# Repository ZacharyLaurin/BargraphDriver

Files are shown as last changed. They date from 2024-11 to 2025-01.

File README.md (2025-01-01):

# Bargraph Driver

For IN-13 / IN-9 Neon Tubes

## Description

Wave

This is a small 21x24mm driver module PCB designed for a single IN-13 or IN-9 neon bargraph tube. It fits on a breadboard and multiple modules can be chained together with U-shaped headers. Each module has an 8-bit DAC with a fixed address, controlled via I2C. The potentiometer is used to adjust the maximum glow length. Here is four tubes acting as a (not very accurate) spectrum analyzer: https://www.youtube.com/shorts/-yOVEOMO8Xs

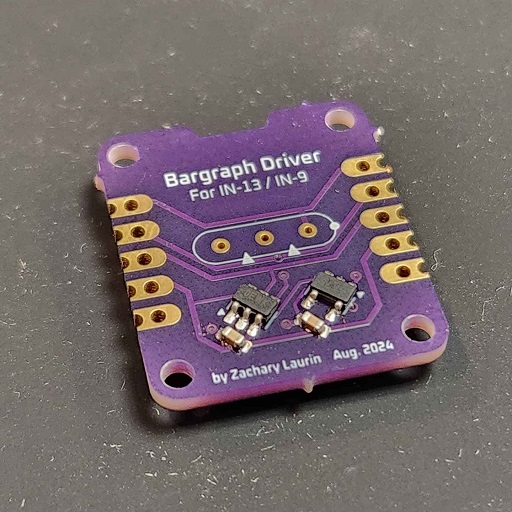
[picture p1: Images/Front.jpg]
Front

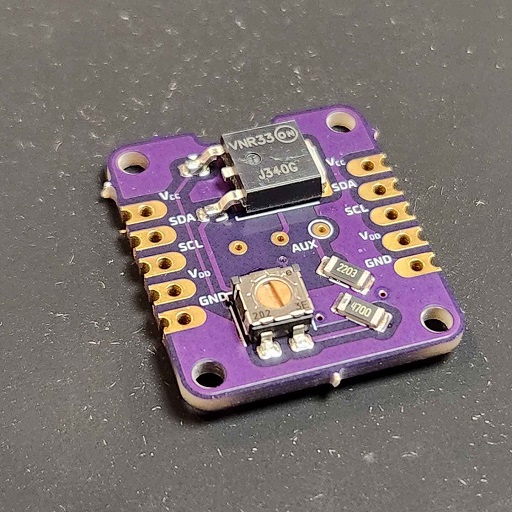
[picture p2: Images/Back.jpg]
Back


In the resources folder you will find the datasheet for the IN-13 as well as the font I used on the silkscreen. I have also included the BOM. I personally got all of the components from Mouser and the boards printed at OSHPark. To power the tubes I am using a [NCH6300HV](https://omnixie.com/products/nch6300hv-nixie-hv-power-module) and to control them an Arduino UNO with this [MCP47X6 library](https://github.com/uChip/MCP47X6).

### Notes

* The SDA pad is right next to the +150V one so watch out as to not accidentally short them while soldering.
* Although the MCP4706's datasheet says that there are eight available addresses, it seems that most electronic suppliers only stock the first four. In my case I had to use two I2C buses to drive as many tubes as I wanted to (and had to do two chains of four tubes).
* You need some sort of frame to hold the tubes in place. I recommend the use of large zip ties near the base to keep them straight.

## Author

Zachary Laurin

## Version History

* 1.0.0
    * Initial Release

## License

This project is licensed under the GNU GPLv3 License - see the LICENSE.md file for details

## Acknowledgments

Thanks a lot to the users of the Arduino, KiCad EDA and Nixie Tubes Discord servers as well as to the people of neonixie-l and the EEVblog forum for their help.

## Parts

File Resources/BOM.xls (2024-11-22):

BARGRAPH DRIVER
Mouser # | Mfr. # | Manufacturer | Customer # | Description | RoHS | Lifecycle | Order Qty. | Price (CAD) | Ext.: (CAD)
863-MJD340G | MJD340G | onsemi |  | Bipolar Transistors - BJT 0.5A 300V 15W NPN | RoHS Compliant By Exemption |  | 10 | $0.806 | $8.06
579-MCP6001T-I/OT | MCP6001T-I/OT | Microchip |  | Operational Amplifiers - Op Amps Single 1.8V 1MHz | RoHS Compliant |  | 10 | $0.435 | $4.35
579-MCP4706A0TECH | MCP4706A0T-E/CH | Microchip |  | Digital to Analog Converters - DAC Sngl 8B NV DAC w/Ext Vref & I2C interfac | RoHS Compliant |  | 3 | $1.38 | $4.14
579-MCP4706A1TECH | MCP4706A1T-E/CH | Microchip |  | Digital to Analog Converters - DAC Sngl 8B NV DAC w/Ext Vref & I2C interface | RoHS Compliant |  | 3 | $1.38 | $4.14
579-MCP4706A2TECH | MCP4706A2T-E/CH | Microchip |  | Digital to Analog Converters - DAC Sngl 8B NV DAC w/Ext Vref & I2C interface | RoHS Compliant |  | 3 | $1.26 | $3.78
579-MCP4706A3TECH | MCP4706A3T-E/CH | Microchip |  | Digital to Analog Converters - DAC Sngl 8B NV DAC w/Ext Vref & I2C interface | RoHS Compliant |  | 3 | $1.38 | $4.14
603-CC603KRX7R7BB104 | CC0603KRX7R7BB104 | YAGEO |  | Multilayer Ceramic Capacitors MLCC - SMD/SMT 16 V 0.1uF X7R 0603 10% | RoHS Compliant |  | 25 | $0.035 | $0.88
229-ST-4ETB202 | ST-4ETB202 | Nidec |  | Trimmer Resistors - SMD 2 KW 4mm SMD single turn Gull wing, top adj. | RoHS Compliant By Exemption |  | 10 | $1.99 | $19.90
279-CRGCQ1206F220K | CRGCQ1206F220K | TE Connectivity |  | Thick Film Resistors - SMD CRGCQ 1206 220K 1% SMD Resistor | RoHS Compliant By Exemption |  | 10 | $0.036 | $0.36
279-CRGCQ1206F470R | CRGCQ1206F470R | TE Connectivity |  | Thick Film Resistors - SMD CRGCQ 1206 470R 1% SMD Resistor | RoHS Compliant By Exemption |  | 10 | $0.038 | $0.38
640-BG305-06A0500LD | BG305-06-A-0500-L-D | Global Connector Technology (GCT) |  | Board to Board & Mezzanine Connectors 6w, 2.54mm Pth Hdr,U Shaped,Dual Insulator, LCP Natural,Tube | RoHS Compliant |  | 10 | $0.744 | $7.44

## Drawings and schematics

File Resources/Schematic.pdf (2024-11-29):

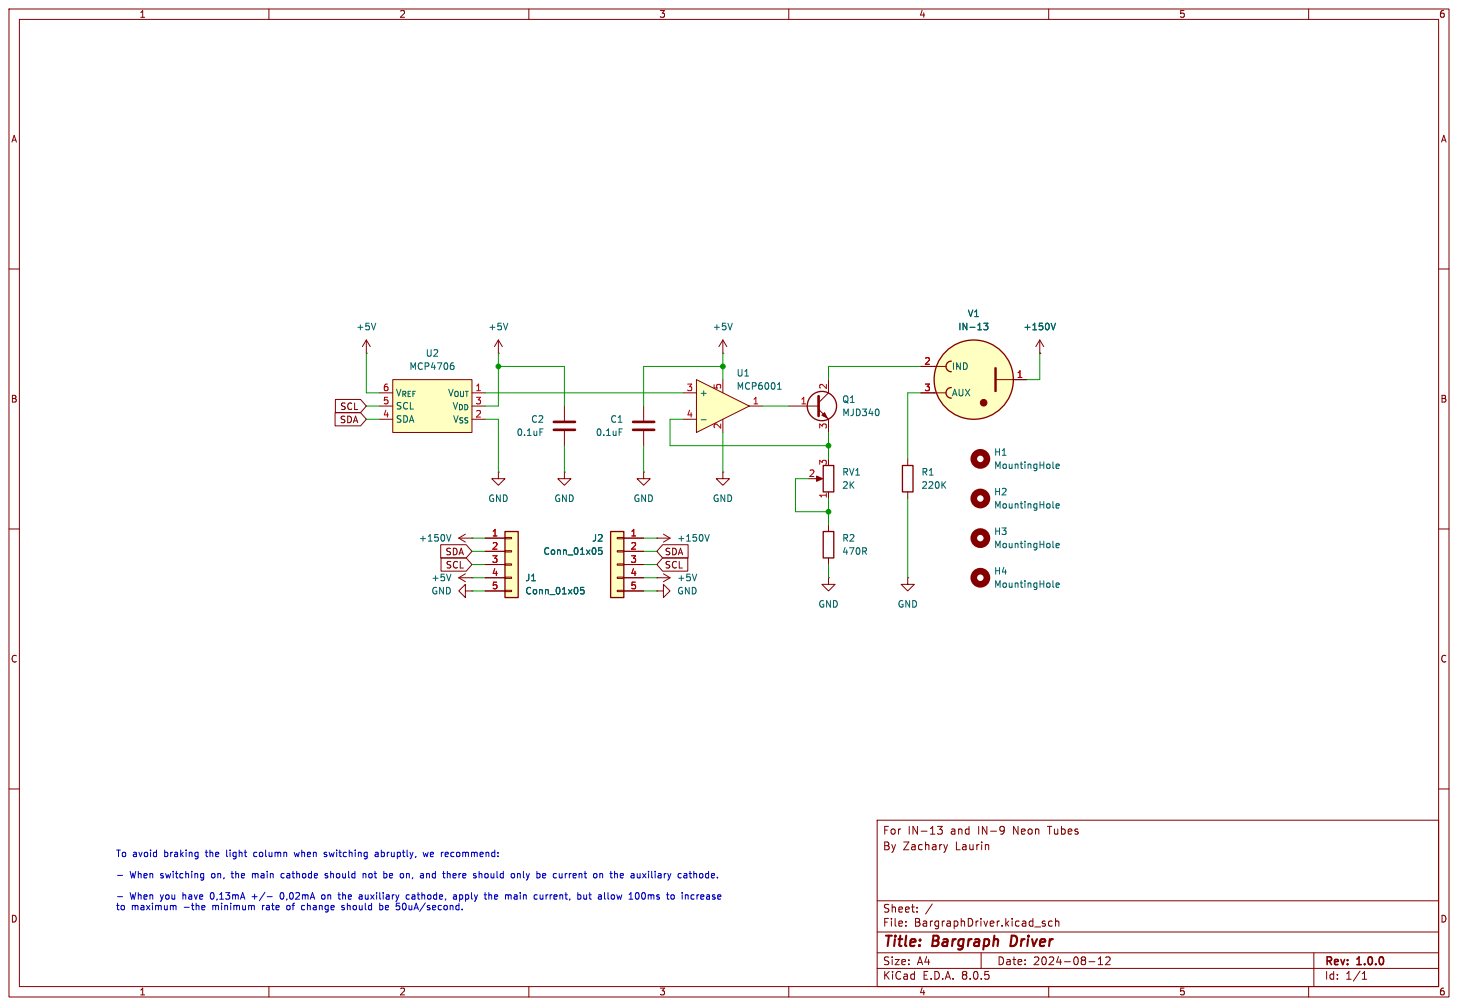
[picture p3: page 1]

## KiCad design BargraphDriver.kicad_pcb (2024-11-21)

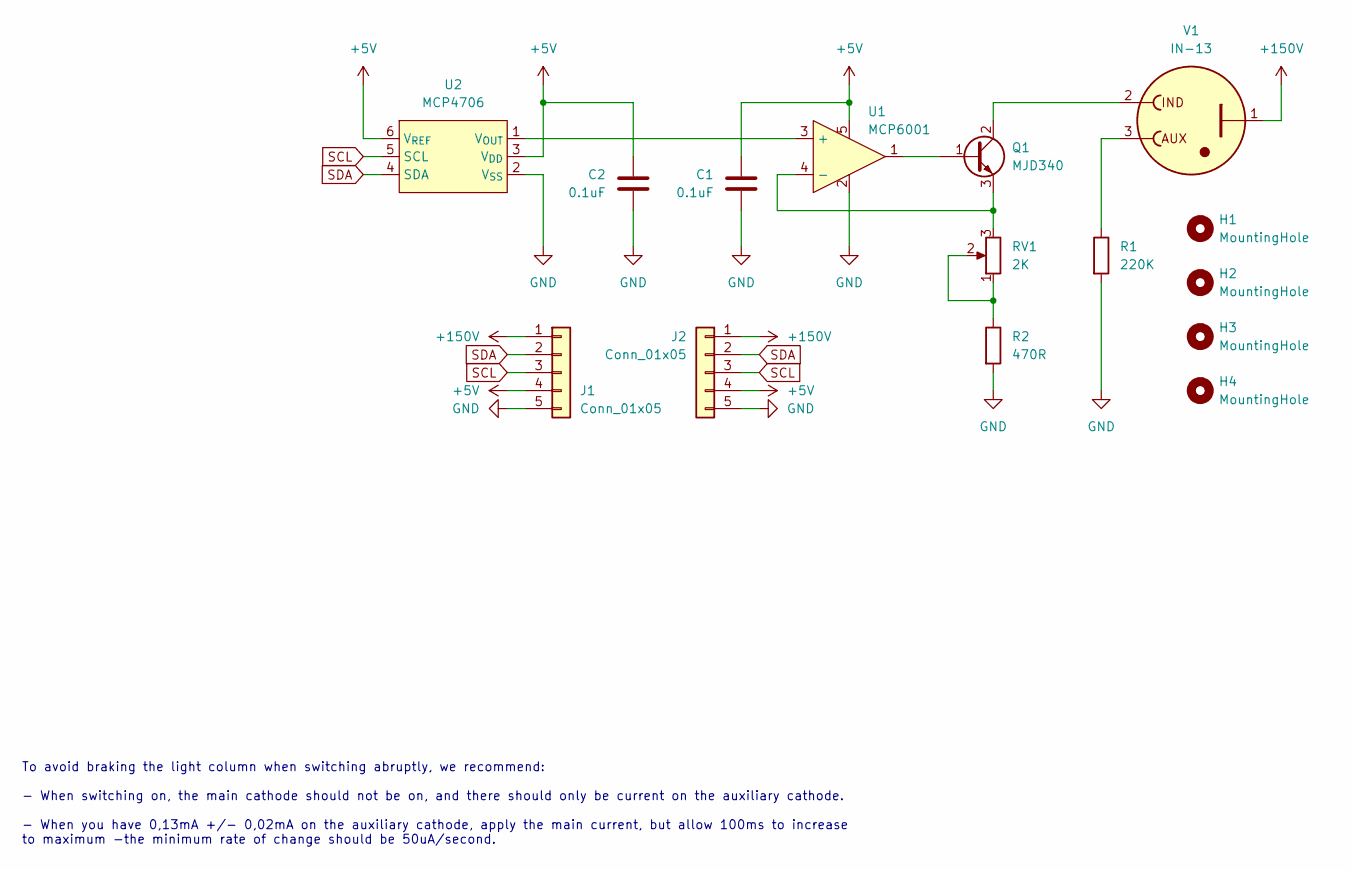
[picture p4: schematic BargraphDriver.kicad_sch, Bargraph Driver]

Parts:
C1, C2: 0.1uF; C_0603_1608Metric
H1, H2, H3, H4: MountingHole; MountingHoleM2
J1, J2: Conn_01x05; Connector
Q1: MJD340; TO-252-2
R1: 220K; R_1206_3216Metric
R2: 470R; R_1206_3216Metric
RV1: 2K; ST-4EB
U1: MCP6001; SOT-23-5
U2: MCP4706; SOT-23-6
V1: IN-13

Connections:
+5V: C1.1, C2.1, J1.4, J2.4, U1.5 (V_{DD}), U2.3 (V_{DD}), U2.6 (V_{REF})
+150V: J1.1, J2.1, V1.1 (A)
GND: C1.2, C2.2, J1.5, J2.5, R1.2, R2.2, U1.2 (GND), U2.2 (V_{SS})
unnamed: Q1.1 (B), U1.1 (OUT)
unnamed: Q1.2 (C), V1.2 (IND_Cathode)
unnamed: Q1.3 (E), RV1.3, U1.4 (-)
unnamed: R2.1, RV1.1, RV1.2
unnamed: U1.3 (+), U2.1 (V_{OUT})
unnamed: R1.1, V1.3 (AUX_Cathode)
SCL: J1.3, J2.3, U2.5 (SCL)
SDA: J1.2, J2.2, U2.4 (SDA)

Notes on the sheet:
To avoid braking the light column when switching abruptly, we recommend: - When switching on, the main cathode should not be on, and there should only be current on the auxiliary cathode. - When you have 0,13mA +/- 0,02mA on the auxiliary cathode, apply the main current, but allow 100ms to increase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

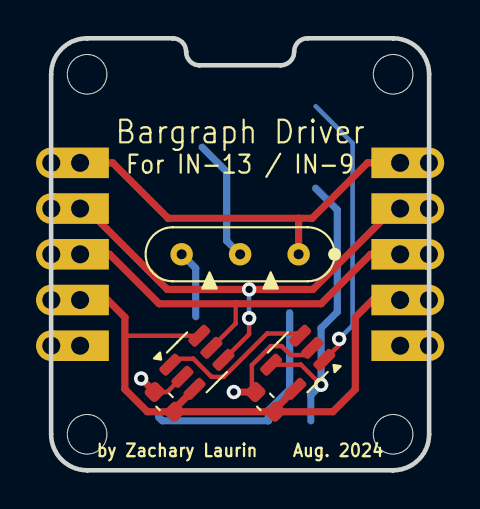
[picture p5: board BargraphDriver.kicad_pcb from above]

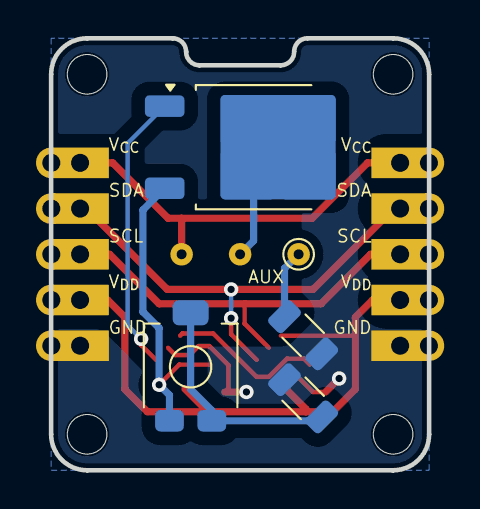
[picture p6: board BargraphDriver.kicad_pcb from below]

Board: 2 copper layers, 21.0 x 24.0 mm, 15 parts (5 on the bottom side), 11 nets.
